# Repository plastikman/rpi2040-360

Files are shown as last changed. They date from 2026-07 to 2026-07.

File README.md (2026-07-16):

# xbox360-rf-rp2040

> ## ✅ Status: WORKING
>
> Drives the Xbox 360 S **Boron Front Panel Module** control bus (start module
> → ring-of-light boot animation → controller sync) from an RP2040-Zero.
>
> **Root cause of a very long bring-up: 3.3V on the wrong pin.** Power must go
> to **pin 8 (`FP_PWR`)**, the module's main rail — **not pin 12
> (`V_3P3STBY`)**, which the schematic labels "3.3V" but is only *standby*
> power. Standby left the chip half-alive: it never clocked, every command
> timed out, the bus sat at a mushy ~2.0V, and USB never enumerated. Move 3.3V
> to **pin 8** and it works with the existing firmware. **If nothing responds,
> confirm 3.3V is on pin 8 — measure pin 8 → GND ≈ 3.3V at the module.**
>
> Wiring (see [`docs/wiring.md`](docs/wiring.md)): **pin 8 = 3.3V, pin 9 = GND,
> pin 2 = DATA → GP3, pin 3 = CLK → GP4, pin 6 = USB D+, pin 5 = USB D−.** Keep
> 1k pull-ups on DATA/CLK.
>
> Diagnostic firmwares from the bring-up live under [`tools/`](tools/).

---

Firmware to drive a salvaged **Xbox 360 S (Slim / "Boron") Front Panel
Module** as a USB PC receiver for wireless Xbox 360 controllers, using a
**Waveshare RP2040-Zero** in place of the console SMC.

Inspired by the [Applied Carbon xboxrf mod](https://www.appliedcarbon.org/xboxrf.html)
(which targets the *phat* RF module), re-implemented for the RP2040 with the
[arduino-pico](https://github.com/earlephilhower/arduino-pico) core.

## What it does

The FPM is itself a self-contained USB device — its USB lines go straight to
the PC. The RP2040 is **not** in the USB data path. It replaces the console
SMC toward the FPM and only:

- reads a **sync button**
- on power-on sends the mandatory Slim **"start module"** command + the
  ring-of-light **boot animation** (visible confirmation the bus works)
- triggers **controller binding** over the FPM's proprietary 2-wire bus

The **module** generates the clock (a **slow** ~hundreds-of-Hz clock on the
Slim, not the phat's ~250 kHz); the host pulls DATA low to start, sets each
bit ~1 ms into the clock-low phase, MSB-first. The Slim needs a mandatory
`0b0000010010` start command before LEDs/sync work, and its sync frame is
**11 bits** (phat's `0b0000000100` + a trailing `1`). Protocol matches the
working [ginokgx/xbox360slimRF](https://github.com/ginokgx/xbox360slimRF).

### Button behaviour

| Action | Result |
|---|---|
| Press | Start controller binding (SYNC) — ring sweeps, then settles on player 1 |

## Hardware

- Waveshare RP2040-Zero (USB-C, dual-core Cortex-M0+, 2MB flash)
- Salvaged Xbox 360 **S (Boron) Front Panel Module**
- 2× 10kΩ pull-up resistors (C_DATA, C_CLK)
- Momentary pushbutton
- USB cable (FPM → PC)
- Printable enclosure: [`hardware/360-rf-board-case-v7.stl`](hardware/360-rf-board-case-v7.stl) (see [`hardware/`](hardware/))

Wiring, full FPM connector pinout, and power rules: see
[`docs/wiring.md`](docs/wiring.md). Short version: the PC cable's 5V powers
the Zero via its `5V` pad, the Zero's `3V3` pad powers the FPM at **pin 8**
(`FP_PWR` — the main rail, **not** pin 12 standby), the USB pair goes to FPM
pins 5/6, and `GP3`/`GP4` are the C_DATA/C_CLK bus.

## Pin map

| RP2040-Zero GPIO | Function | FPM pin |
|---|---|---|
| `GP5` | Sync button (to GND, internal pull-up) | — |
| `GP3` | C_DATA (+10k pull-up) | 2 |
| `GP4` | C_CLK  (+10k pull-up) | 3 |

## Build & flash

Uses the arduino-pico core. FQBN: `rp2040:rp2040:waveshare_rp2040_zero`.

### arduino-cli

```bash
# one-time: add the core
arduino-cli config add board_manager.additional_urls \
  https://github.com/earlephilhower/arduino-pico/releases/download/global/package_rp2040_index.json
arduino-cli core update-index
arduino-cli core install rp2040:rp2040

# compile
arduino-cli compile --fqbn rp2040:rp2040:waveshare_rp2040_zero .

# flash: hold BOOT, tap RESET so the board mounts as a USB drive (RPI-RP2),
# then either upload or drag-drop the .uf2
arduino-cli upload --fqbn rp2040:rp2040:waveshare_rp2040_zero -p /dev/ttyACM0 .
```

### Arduino IDE

1. Add the board manager URL above (Preferences → Additional Boards URLs).
2. Boards Manager → install "Raspberry Pi Pico/RP2040".
3. Select **Waveshare RP2040 Zero**.
4. Open `xbox360-rf-rp2040.ino`, Upload.

## Protocol notes

The Boron FPM two-wire bus and command frames are from community reverse
engineering. Command table lives in [`XboxRF.cpp`](XboxRF.cpp).

- [drtrinity — Reversing the RF board / SMC two-wire interface](https://drtrinity.uk/blog/2025/05/12/reversing-the-rf-board-1) (Slim/Boron, primary source)
- [agarmash.com writeup](https://agarmash.com/posts/xbox-360-controller-receiver/) (phat background)
- [tkkrlab wiki — XBOX 360 RF Module](https://tkkrlab.nl/wiki/XBOX_360_RF_Module) (phat)

## Status — working (controller pairs + registers input)

Confirmed end-to-end: the module **enumerates on USB**, a controller **pairs**
(RP2040 sync button → controller sync) and **registers input** in Windows
`joy.cpl`. On boot the firmware sends the Slim `start module` command then the
ring-of-light **boot animation** (visible confirmation); the sync command
completes over the bus.

**Windows driver:** the module reports `USB\VID_045E&PID_02A9`. Bind the stock
in-box driver by force-picking it — **no `.inf` edit, no signature disable.**
Full steps in **[`docs/windows-driver.md`](docs/windows-driver.md)**; short
version: Device Manager → the device → Update driver → Browse → *Let me pick
from a list* → Microsoft → **Xbox 360 Wireless Receiver for Windows** (accept
the incompatibility warning).

**Ring-of-light:** boot plays the animation and rests on **player 1** lit; a
sync press runs the **searching sweep**, then **all-four flash** (connected),
then settles back to player 1. LED codes were found on-hardware with
[`tools/led-explorer`](tools/led-explorer): `0x088` = sweep, `0x0A1` =
quadrant 1, `0x0C0` = all-four flash. (The RP2040 isn't in the USB-side XInput
player assignment, so it always shows **player 1** — correct for a single
controller.)

Protocol follows [ginokgx/xbox360slimRF](https://github.com/ginokgx/xbox360slimRF):
module-clocked, **slow** clock (hundreds of Hz, not the phat's 250 kHz),
`start module` init `0b0000010010`, ring boot animation `0b0010000101`, 11-bit
sync `0b00000001001`, data set ~1 ms into the clock-low phase, MSB-first.

**The bug that cost the whole bring-up:** 3.3V was on **pin 12
(`V_3P3STBY`, standby power)** instead of **pin 8 (`FP_PWR`, main power)**.
Standby only half-powered the chip — it never clocked, commands timed out, the
bus idled at a mushy ~2.0V, and USB wouldn't enumerate. Fixed by moving 3.3V to
**pin 8**. Lesson: the schematic's "3.3V" pin (12) is *standby*; the module's
logic runs off **pin 8** — verify pin 8→GND ≈ 3.3V at the module.

Diagnostic firmwares (bus-monitor, bus-capture, bus-health, smc-clock-test)
live under [`tools/`](tools/).

## Windows driver

The receiver uses the **official in-box Xbox 360 Wireless Receiver driver** —
force-picked onto the device (`VID_045E&PID_02A9`), no `.inf` editing or
signature-enforcement changes required. Step-by-step: **[`docs/windows-driver.md`](docs/windows-driver.md)**.

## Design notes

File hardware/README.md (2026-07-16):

# Hardware

`360-rf-board-case-v7.stl` — printable enclosure for the Xbox 360 S (Boron)
FPM receiver build (RP2040-Zero + FPM). **v7** is the current revision.

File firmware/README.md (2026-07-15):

# Prebuilt firmware

`xbox360-rf-rp2040.uf2` — compiled binary, ready to flash without a toolchain.

- **Board:** Waveshare RP2040-Zero (`rp2040:rp2040:waveshare_rp2040_zero`)
- **Core:** arduino-pico (earlephilhower) `rp2040:rp2040@5.6.1`
- **Library:** Adafruit NeoPixel `1.15.5` (onboard WS2812 status LED)
- **Built from:** the sketch in the repo root

## Onboard RGB status (WS2812 on GP16)

| Colour | Meaning |
|---|---|
| Solid green | Powered and running (shows immediately on power-up) |
| Blue flash | Sync command sent OK |
| Red flash | Control-bus timeout — FPM didn't respond |

If you see **solid green**, the Zero is powered and the firmware is running —
so any "device doesn't enumerate" problem is on the module/USB side, not the Zero.

## Flash it

1. Hold **BOOT** on the RP2040-Zero, tap **RESET** (or plug in USB-C while
   holding BOOT). It mounts as a USB drive named `RPI-RP2`.
2. Drag `xbox360-rf-rp2040.uf2` onto that drive. The board reboots and runs.

## Rebuild

```bash
arduino-cli lib install "Adafruit NeoPixel"
arduino-cli compile --fqbn rp2040:rp2040:waveshare_rp2040_zero .
```

> Verified working on hardware: module enumerates over USB, controller pairs
> and registers input, and the ring plays boot / sweep / player-1 / connect
> animations. Power **must** go to FPM pin 8 (see the repo README / docs/wiring.md).

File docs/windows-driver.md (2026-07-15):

# Windows driver install

The FPM enumerates as a standard USB device but reports
`USB\VID_045E&PID_02A9`, which the in-box Xbox 360 driver doesn't bind
automatically. You don't need to edit any `.inf` or disable driver-signature
enforcement — just **force-pick the stock Microsoft driver**, which is already
on every Windows 10/11 machine. This is the method that worked here, cleanly.

## Steps (the easy way — no file editing)

1. Connect the receiver's USB to the PC. In **Device Manager** it appears as an
   unknown / "Other" device (⚠️), Hardware ID `USB\VID_045E&PID_02A9`.
2. Right-click it → **Update driver**.
3. **Browse my computer for drivers**.
4. **Let me pick from a list of available drivers on my computer.**
5. If asked for a device category, choose **Xbox 360 Peripherals**
   (or just untick **Show compatible hardware** to see all).
6. Manufacturer **Microsoft** → model **Xbox 360 Wireless Receiver for
   Windows** → **Next**.
7. Accept the **"this driver may not be compatible / not recommended"**
   warning.

The device renames itself to **Xbox 360 Wireless Receiver for Windows** with no
error mark. That's it — the binding **persists across reboots**.

## Verify

1. Press the **sync button** on the adapter (Zero LED flashes blue; the module
   ring does the searching sweep).
2. Press the **sync button on the controller**.
3. The controller connects (its ring settles to a player quadrant).
4. Run **`joy.cpl`** (Win+R → `joy.cpl`) — the controller shows up; sticks and
   buttons register. Or just launch a game.

## Fallback — editing the `.inf` (only if force-pick isn't offered)

Some locked-down Windows setups don't expose the manual driver list. If so:

1. Copy `C:\Windows\System32\DriverStore\FileRepository\xusb22.inf_amd64_*\`
   to a writable folder, e.g. `C:\xbox360driver\`.
2. In `xusb22.inf`, search for `PID_0719`. For each line, add a duplicate below
   it with your PID, e.g.:
   ```
   %XUSB22.DeviceName%=XUSB22_Install, USB\VID_045E&PID_02A9
   ```
   (do it in both `NTamd64` and `NTx86` sections if present; change only the
   PID).
3. Editing the `.inf` breaks its signature, so **disable driver-signature
   enforcement** for the install: Settings → System → Recovery → Advanced
   startup → Restart now → Troubleshoot → Advanced options → Startup Settings →
   Restart → press **7**. Then Update driver → Browse → `C:\xbox360driver\`.

The force-pick method (above) avoids all of this and is strongly preferred.

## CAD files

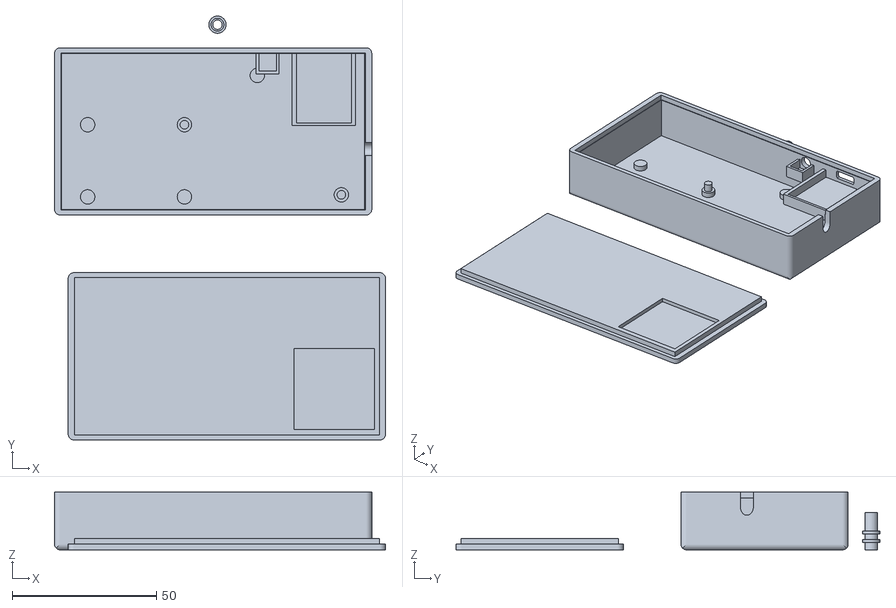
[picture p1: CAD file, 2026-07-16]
hardware/360-rf-board-case-v7.stl
114.8 x 147.0 x 20.0

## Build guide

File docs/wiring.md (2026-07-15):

# Wiring — RP2040-Zero ↔ Xbox 360 S (Boron) FPM

## Principle

The Front Panel Module is a self-contained USB device. Its **USB lines go
straight to the PC** and never touch the RP2040. The RP2040 only drives the
FPM's 2-wire control bus (power LED + controller binding) and reads a sync
button.

## Physical connector layout

As seen on the board — **`■` is the square pad = pin 1** (the pin-1 marker).
Top row 1–6, bottom row 13→7:

```
   ■1    2    3    4    5    6
   13   12   11   10    9    8    7
```

The six wires you actually connect:

```
   pin  signal        connect to
   ---  ------------  ----------------------------
    8   FP_PWR        RP2040 3V3    ⚠ THIS is the 3.3V pin — the module's MAIN
                                     power rail. NOT pin 12 (see warning below).
    9   GND1          RP2040 GND / common ground
    2   C_DATA        RP2040 GP3    (+1k pull-up to 3V3)
    3   C_CLK         RP2040 GP4    (+1k pull-up to 3V3)
    6   D+            PC USB D+ (green)
    5   D−            PC USB D− (white)
   (every other pin — including pin 12 — leave unconnected)
```

> ### ⚠️ Power goes on pin 8, NOT pin 12
> This is the single mistake that cost the entire bring-up. The X819886
> schematic labels **pin 12 = `V_3P3STBY`** (3.3V **standby**) and **pin 8 =
> `FP_PWR`** — but standby power only feeds a tiny always-on domain (enough for
> button sense and a mushy ~2.0V on the bus), **not** the SC14470's main logic.
> Powering pin 12 leaves the chip half-alive: it never clocks, never enumerates
> over USB, and the control bus reads ~2.0V. **Feed 3.3V to pin 8 (FP_PWR) —
> the main rail — and the module comes fully alive.** Verify by measuring
> **pin 8 → GND ≈ 3.3V** at the module.

### Reference: drtrinity's Boron → Pico tap points

The same signals can be tapped from the on-board pad row (between the ribbon
connector and the sync button). This annotated photo maps them by colour:

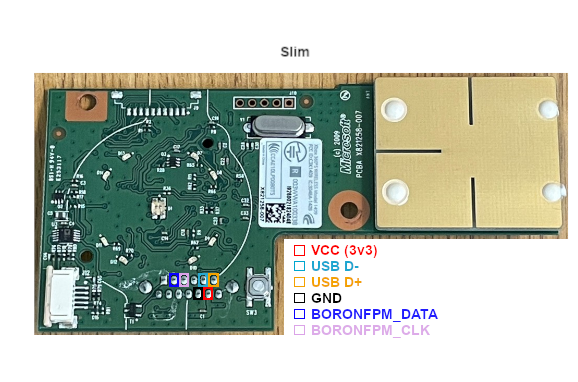
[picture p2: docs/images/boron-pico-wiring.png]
Boron → Pico wiring


> red = VCC (3.3V), black = GND, dark-blue = BORONFPM_DATA, pink =
> BORONFPM_CLK, cyan = USB D−, orange = USB D+.
>
> Image credit: **drtrinity**, *"Reversing the Xbox 360 Front Power Module:
> The SMC Two-Wire Interface"* —
> <https://drtrinity.uk/blog/2025/05/12/reversing-the-rf-board-1>

## Boron FPM connector pinout (X819886-001)

From the official BORON CONN schematic. We use only 6 of the 17 pins.

| Pin | Signal | Direction | Use here |
|----:|---|---|---|
| 1 | FP_TEMP_P | temp sensor | skip |
| **2** | **C_DATA** | control-bus data (BI) | → RP2040 `GP3` (+10k pull-up) |
| **3** | **C_CLK** | control-bus clock (FPM drives) | → RP2040 `GP4` (+10k pull-up) |
| 4 | SPARE1 | — | skip |
| **5** | **D−** | USB differential | → USB to PC |
| **6** | **D+** | USB differential | → USB to PC |
| 7 | FP_TEMP_N | temp sensor | skip |
| **8** | **FP_PWR** | **main 3.3V power** | ← RP2040-Zero `3V3` pad |
| **9** | **GND1** | ground | → GND |
| 10 | ODD_EJECT | eject button out | skip |
| **11** | **GND2** | ground | → GND |
| 12 | V_3P3STBY | 3.3V **standby** (does NOT power the logic) | **skip** — see warning above |
| 13 | BINDSW_N | bind button out | skip (we sync over the bus) |
| 14 | ME1 | mount / GND | GND (optional) |
| 15 | ME2 | mount / GND | GND (optional) |
| 16 | ME3 | mount / GND | GND (optional) |
| 17 | ME4 | mount / GND | GND (optional) |

Note from schematic: `BORONFPMPORT_DX IS A USB DIFFERENTIAL PAIR` (pins 5/6).

## Connections

| RP2040-Zero | ↔ | FPM pin | Notes |
|---|---|---|---|
| `5V` pad | ← | USB VBUS (5V, from the PC cable) | powers the Zero; 5V as **INPUT** |
| `3V3` pad | → | **8** FP_PWR (main 3.3V — NOT pin 12) | Zero's regulator powers the FPM |
| `GND` | ↔ | **9 / 11** (+ ME1–4) | common ground |
| `GP3` | ↔ | **2** C_DATA | + 10kΩ pull-up to 3V3 |
| `GP4` | ← | **3** C_CLK | + 10kΩ pull-up to 3V3 (FPM drives it) |
| `GP5` | ← | sync button → GND | internal pull-up in firmware (moved off GP2) |

### USB routing

The PC's USB cable: **D+ → FPM pin 6, D− → FPM pin 5, GND → pin 9/11**, and
its **5V → the Zero's `5V` pad** (the FPM itself runs on 3.3V from the Zero,
not on USB 5V).

### Pull-ups and decoupling

- The console provides 100kΩ pull-ups on the bus lines *from the motherboard*.
  A salvaged FPM has none, so add **1–10kΩ pull-ups on C_DATA and C_CLK to 3V3**.
- A ~10–100 µF cap across the module's 3.3V (pin 8) / GND near the connector is
  good practice for clean power.

## USB / power rules

- **One 5V source at a time.** Power the Zero from the PC cable's 5V (into the
  `5V` pad). Do **not** also plug the Zero's USB-C into a PC simultaneously —
  the Zero may lack backfeed protection and the rails would fight.
- Use the Zero's **USB-C only for flashing firmware**, module unplugged.

## Before powering on

1. Confirm silkscreen: `3V3` on the Zero is the regulator **output**; feed it
   to FPM **pin 8** (FP_PWR), **not** pin 12. Never put 5V on it.
2. Double-check pins 5/6 (D−/D+) and 2/3 (C_DATA/C_CLK) against your actual
   board with a multimeter — pin numbering/orientation on a bare connector is
   easy to mirror.
3. Verify FPM current draw fits the Zero's LDO headroom (low-power; fine).

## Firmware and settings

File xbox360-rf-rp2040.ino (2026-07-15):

// Xbox 360 S (Slim / "Boron") FPM -> USB desktop adapter, RP2040-Zero edition.
//
// The RP2040 replaces the console SMC toward the Front Panel Module. It is
// NOT in the USB data path: the FPM's USB lines run straight to the PC and
// enumerate on power alone. This firmware only drives the control bus:
//   - power-on: send the mandatory Slim "start module" command, then the
//     ring-of-light boot animation (visible confirmation the bus works)
//   - sync button: trigger controller binding (11-bit Slim sync frame)
//
// Protocol per the working Slim implementation ginokgx/xbox360slimRF: the
// MODULE generates a slow (~hundreds of Hz) clock; we sync to it.
//
// Onboard RGB status (WS2812 on GP16):
//   solid green  -> running
//   blue flash   -> command sent OK
//   red flash    -> control-bus timeout (module didn't clock)
//
// Board: Waveshare RP2040-Zero   FQBN: rp2040:rp2040:waveshare_rp2040_zero
// Wiring/pinout: docs/wiring.md

#include <Adafruit_NeoPixel.h>
#include "XboxRF.h"

constexpr uint8_t PIN_BUTTON = 5;   // sync button to GND (moved off GP2)
constexpr uint8_t PIN_DATA   = 3;   // FPM pin 2  C_DATA
constexpr uint8_t PIN_CLK    = 4;   // FPM pin 3  C_CLK (module drives it)
constexpr uint8_t PIN_RGB    = 16;  // onboard WS2812

constexpr uint16_t DEBOUNCE_MS    = 30;
constexpr uint16_t BOOT_WAIT_MS   = 3500;  // let the FPM boot before talking
constexpr uint16_t CMD_GAP_MS     = 50;
constexpr uint16_t SYNC_WINDOW_MS = 4000;  // searching/pairing window
constexpr uint8_t  INIT_RETRIES   = 30;    // retry init until the FPM answers
constexpr uint8_t  LVL            = 32;

XboxRF rf(PIN_DATA, PIN_CLK);
Adafruit_NeoPixel pixel(1, PIN_RGB, NEO_GRB + NEO_KHZ800);

void led(uint8_t r, uint8_t g, uint8_t b) {
  pixel.setPixelColor(0, pixel.Color(r, g, b));
  pixel.show();
}
void ledIdle() { led(0, LVL, 0); }

void ledResult(bool ok) {
  for (uint8_t i = 0; i < (ok ? 2 : 3); i++) {
    led(ok ? 0 : LVL, 0, ok ? LVL : 0);
    delay(120);
    led(0, 0, 0);
    delay(90);
  }
  ledIdle();
}

void setup() {
  Serial.begin(115200);
  pixel.begin();
  ledIdle();  // green immediately: Zero is powered and running

  pinMode(PIN_BUTTON, INPUT_PULLUP);
  rf.begin();

  delay(BOOT_WAIT_MS);

  // Init with retry: the module isn't always ready at a fixed delay after
  // power-up, and a single attempt that times out would leave the ring dark
  // until a replug. Keep trying until the control-bus commands succeed.
  bool inited = false;
  for (uint8_t attempt = 0; attempt < INIT_RETRIES && !inited; attempt++) {
    bool a = rf.startModule();
    delay(CMD_GAP_MS);
    bool b = rf.bootAnimation();
    inited = a && b;
    Serial.printf("init attempt %d: start=%d boot=%d\n", attempt + 1, a, b);
    if (!inited) {           // brief red blink, then retry
      led(LVL, 0, 0);
      delay(400);
      led(0, 0, 0);
      delay(200);
    }
  }

  if (inited) {
    delay(CMD_GAP_MS);
    rf.ledPlayer1();
  }
  ledResult(inited);
}

void loop() {
  static bool wasDown = false;
  static uint32_t downAt = 0;

  bool isDown = (digitalRead(PIN_BUTTON) == LOW);
  uint32_t now = millis();

  if (isDown && !wasDown) {
    wasDown = true;
    downAt = now;
  } else if (!isDown && wasDown) {
    wasDown = false;
    if (now - downAt >= DEBOUNCE_MS) {
      Serial.println("sync");
      led(0, 0, LVL);            // Zero LED blue while syncing
      rf.sweep();                // ring shows the searching sweep
      bool ok = rf.syncController();
      delay(SYNC_WINDOW_MS);     // pairing window (sweep runs)
      rf.ledAllFlash();          // all-four flash = connected
      delay(1200);
      rf.ledPlayer1();           // settle back to player 1
      ledResult(ok);
    }
  }
}

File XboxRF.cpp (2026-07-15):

#include "XboxRF.h"

// Command frames (MSB-first), from the working Slim implementation
// ginokgx/xbox360slimRF (https://github.com/ginokgx/xbox360slimRF).
//
//   START (0b0000010010) — mandatory Slim "start module" init; without it
//                          the LEDs/sync don't work.
//   BOOT  (0b0010000101) — ring-of-light boot animation (= 0x085).
//   SYNC  (0b00000001001) — phat sync 0b0000000100 + a trailing 1; 11 bits.
//   OFF   (0b0010000000) — LEDs off.
// LED codes verified on-hardware with tools/led-explorer:
//   0x088 = rotating "searching" sweep
//   0x0A1 = quadrant 1 lit (player 1)
//   0x0C0 = all four quadrants flash (sync-complete confirm)
static const uint8_t CMD_START[10]    = {0, 0, 0, 0, 0, 1, 0, 0, 1, 0};
static const uint8_t CMD_BOOT[10]     = {0, 0, 1, 0, 0, 0, 0, 1, 0, 1};  // 0x085
static const uint8_t CMD_SYNC[11]     = {0, 0, 0, 0, 0, 0, 0, 1, 0, 0, 1};
static const uint8_t CMD_SWEEP[10]    = {0, 0, 1, 0, 0, 0, 1, 0, 0, 0};  // 0x088
static const uint8_t CMD_PLAYER1[10]  = {0, 0, 1, 0, 1, 0, 0, 0, 0, 1};  // 0x0A1
static const uint8_t CMD_ALLFLASH[10] = {0, 0, 1, 1, 0, 0, 0, 0, 0, 0};  // 0x0C0
static const uint8_t CMD_OFF[10]      = {0, 0, 1, 0, 0, 0, 0, 0, 0, 0};

XboxRF::XboxRF(uint8_t dataPin, uint8_t clkPin)
    : _data(dataPin), _clk(clkPin) {}

void XboxRF::begin() {
  // Idle: both lines released, held high. External ~1k pull-ups recommended;
  // the module (not this MCU) drives CLK.
  pinMode(_clk, INPUT_PULLUP);
  pinMode(_data, INPUT_PULLUP);
}

void XboxRF::releaseData() {
  digitalWrite(_data, HIGH);
  pinMode(_data, INPUT_PULLUP);
}

// Block until CLK differs from prevLevel (an edge), or timeout.
bool XboxRF::waitClockChange(int prevLevel, uint32_t timeoutUs) {
  uint32_t start = micros();
  while (digitalRead(_clk) == prevLevel) {
    if (micros() - start > timeoutUs) return false;
  }
  return true;
}

bool XboxRF::sendData(const uint8_t* cmd, uint8_t nbits) {
  // Start: pull DATA low while the (module-driven) clock idles high.
  pinMode(_data, OUTPUT);
  digitalWrite(_data, LOW);

  int prev = digitalRead(_clk);  // usually HIGH at idle
  for (uint8_t i = 0; i < nbits; i++) {
    // Wait for the clock to fall...
    if (!waitClockChange(prev, CLK_TIMEOUT_US)) { releaseData(); return false; }
    prev = digitalRead(_clk);

    // ...settle into the low phase, then present the bit.
    delayMicroseconds(1000);
    digitalWrite(_data, cmd[i] ? HIGH : LOW);

    // Wait for the clock to rise (module latches the bit).
    if (!waitClockChange(prev, CLK_TIMEOUT_US)) { releaseData(); return false; }
    prev = digitalRead(_clk);
  }

  releaseData();
  return true;
}

bool XboxRF::startModule()    { return sendData(CMD_START, 10); }
bool XboxRF::bootAnimation()  { return sendData(CMD_BOOT, 10); }
bool XboxRF::syncController() { return sendData(CMD_SYNC, 11); }
bool XboxRF::sweep()          { return sendData(CMD_SWEEP, 10); }
bool XboxRF::ledPlayer1()     { return sendData(CMD_PLAYER1, 10); }
bool XboxRF::ledAllFlash()    { return sendData(CMD_ALLFLASH, 10); }
bool XboxRF::ledsOff()        { return sendData(CMD_OFF, 10); }

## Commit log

2026-07-14 Initial RP2040-Zero firmware for Xbox 360 RF module adapter
    arduino-pico firmware that replaces the original ATtiny25 front-panel
    controller. Reads the sync button and drives the module's 2-wire control
    bus (LED ring, sync, power-off). Not in the USB data path.
    [XboxRF.cpp, xbox360-rf-rp2040.ino]
2026-07-14 Retarget firmware to Xbox 360 S (Boron) Front Panel Module
    The user's salvaged board is a Slim/S FPM, not a phat RF module. Adapt to
    the Boron two-wire control bus per the 2025 drtrinity reverse engineering:
    250 kHz FPM-driven clock, 10-bit ACK+command frame, falling-edge sampling,
    and the Slim command set (power LED, bind/sync, wireless toggle). Document
    the full BORON CONN (X819886-001) pinout in docs/wiring.md.
2026-07-14 Add prebuilt firmware binary (xbox360-rf-rp2040.uf2)
    Compiled with arduino-pico rp2040:rp2040@5.6.1 for the Waveshare
    RP2040-Zero. Shipped so the board can be flashed by drag-drop without a
    local toolchain. 64 KB flash, valid UF2.
2026-07-14 Add WS2812 onboard status LED (green=alive, blue=sync, red=bus timeout)
    The RP2040-Zero has no plain power LED, only a WS2812 RGB on GP16. Drive it
    via Adafruit NeoPixel so a glance confirms the board is powered/running:
    solid green on boot, blue flash on sync OK, cyan on wireless toggle, red
    flash on control-bus timeout. Rebuild the shipped .uf2.
2026-07-14 Add passive bus-monitor diagnostic firmware
    Watches C_DATA/C_CLK without driving them and reports edge activity + idle
    levels over USB serial, plus a WS2812 summary (green=CLK idle high,
    red=CLK stuck low, blue=CLK toggling). For diagnosing why a known-good FPM
    won't respond on the control bus.
    [bus-monitor.ino]
2026-07-14 Add bus-capture mini logic-analyzer firmware
    Records every CLK/DATA transition for ~4s at power-up into RAM and dumps
    them over USB serial, to capture the FPM's power-on handshake burst for
    protocol decoding.
2026-07-14 bus-capture: mirror dump to Serial1 (UART0 on GP0)
    Output now goes to both USB-C CDC and the hardware UART (TX=GP0, 115200)
    so an external USB-serial adapter can read the capture without tying up
    the Zero's USB-C.
2026-07-14 bus-capture: switch to triggered capture (robust to boot timing)
    Sits armed and grabs the burst the instant the bus moves, then re-arms.
    Lets you leave the Zero running and power-cycle only the module to catch
    the FPM power-on handshake, instead of racing the 4s boot window.
2026-07-14 bus-capture: arm immediately (no USB-serial wait)
    Removes the up-to-2s wait for USB CDC so the trigger is armed within ms of
    boot, catching the FPM power-on burst on a shared power cycle. Read the
    dump via the UART adapter (Serial1/GP0), whose COM port survives the cycle.
2026-07-15 Add bus-health live monitor + draft bus-probe
    bus-health continuously attempts a benign control-bus transaction and shows
    green=ok / red=fail live, for finding an intermittent connection by wiggling
    wires. Also includes the active bus-probe draft.
    [bus-health.ino, bus-probe.ino]
2026-07-15 Add smc-clock-test: RP2040 generates the clock
    bus-health proved the FPM never clocks (0% with the FPM-provides-clock
    approach). This test has the RP2040 generate the clock itself and clocks out
    power-LED on/off every 2s so the module's LED can confirm the SMC-as-clock-
    master direction visually.
2026-07-15 Rework driver for the real Slim (Boron) protocol
    Based on the working ginokgx/xbox360slimRF implementation:
    - module generates a SLOW clock (hundreds of Hz, not phat's 250 kHz) -> use
    a generous edge timeout; earlier short timeouts caused false 0% results
    - send the mandatory Slim "start module" command (0b0000010010) at power-on,
    then the ring-of-light boot animation as a visual bus-works check
    - 11-bit sync frame (phat's 0b0000000100 + trailing 1)
    - set data ~1 ms into the clock-low phase, MSB-first, sync to module edges
    Rebuild shipped firmware .uf2.
    [XboxRF.cpp, xbox360-rf-rp2040.ino]
2026-07-15 README: mark as NOT WORKING; needs logic analysis
    The Boron FPM control bus never clocks for us, so no command completes.
    Hardware/wiring/pinout/firmware are all confirmed correct; the blocker is the
    module's undocumented control-bus behavior. No published working reference
    exists for the 13-pin Boron FPM (ginokgx targets a 9-pin phat-style module).
    Unblocking requires a logic-analyzer capture of a live Xbox 360 S console's
    SMC-FPM traffic.
2026-07-15 README: WORKING — root cause was 3.3V on the wrong pad
    Both modules (incl. the one earlier misdiagnosed as dead) work once VCC is on
    the correct pad. Control bus drives start/boot-animation/sync; USB enumerates.
    Document the correct pad-row wiring and the verify-VCC-at-the-module lesson.
2026-07-15 README: confirmed fully working (controller pairs + input)
    USB enumerates, controller pairs and registers in joy.cpl. Document the
    driver force-pick for VID_045E&PID_02A9 and the cosmetic player-quadrant LED
    limitation (RP2040 isn't in the USB-side player assignment).
2026-07-15 Add led-explorer: step through candidate ring LED commands
    Each sync-button press sends the next candidate LED frame and reports it over
    serial, to empirically find the Boron's "spin/searching" animation and the
    "light quadrant 1" command (not documented for the Slim). Findings get baked
    into the main firmware.
2026-07-15 docs: physical connector layout + credited Boron->Pico tap photo
    Add a physical two-row connector diagram (square pad = pin 1) with the six
    wires to connect, flagging pin 12 (V_3P3STBY) as the one that must be right.
    Include drtrinity's annotated Boron->Pico pad-row photo, credited with a link.
2026-07-15 Add ring animations: searching sweep + player-1 + connect flash
    Using LED codes found on-hardware via tools/led-explorer (0x088 sweep,
    0x0A1 quadrant 1, 0x0C0 all-four flash):
    - boot rests on player 1 lit
    - sync button: sweep -> sync -> pairing window -> all-four flash -> player 1
    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
2026-07-15 docs: 3.3V goes to pin 8 (FP_PWR), not pin 12 (V_3P3STBY standby)
    The real root cause: pin 12 is 3.3V STANDBY (feeds only a standby domain, not
    the SC14470 main logic) — powering it left the chip half-alive (no clock, no
    USB, ~2.0V bus). Main power is pin 8 (FP_PWR). Correct all wiring docs/pinout
    tables and the root-cause notes accordingly.
2026-07-15 Move sync button from GP2 to GP5
    Lets a board with a damaged GP2 still be used. DATA/CLK/RGB unchanged
    (GP3/GP4/GP16). Rebuild shipped firmware .uf2 and update docs.
    [xbox360-rf-rp2040.ino]
2026-07-15 tools: move button to GP5 and rebuild all diagnostic uf2s
    bus-monitor and led-explorer used the button on GP2; move both to GP5 to match
    the main firmware (usable on a GP2-damaged board). Recompile and refresh the
    prebuilt .uf2 for all five tools (bus-monitor, bus-capture, bus-health,
    smc-clock-test, led-explorer).
    [bus-monitor.ino, led-explorer.ino]
2026-07-15 docs: add Windows driver install guide (force-pick method)
    Document the exact working install: force-pick the in-box "Xbox 360 Wireless
    Receiver for Windows" driver onto VID_045E&PID_02A9 via Device Manager's
    "let me pick from a list" — no .inf edit, no signature-enforcement disable.
    Include a verify section and the .inf-edit fallback. Link it from the README.
2026-07-15 led-explorer: add control-range candidates for radio/controllers-off
    Append 0x008/0x009/0x00A and 0x010/0x011/0x013 (controller-toggle and
    radio-control range) as indices 22-27 so the "turn radio off" command can be
    found on hardware, to wire onto a long-press.
2026-07-15 docs: remove unsupported long-press/radio-off claim
    The firmware only does short-press sync; there is no long-press or wireless-
    radio toggle. Fix the button-behaviour table and the RGB-status table (drop
    the stale cyan/"wireless toggle" line) to match what actually ships.
2026-07-15 Add printable case STL (hardware/360-rf-board-case.stl)
    Enclosure for the RP2040-Zero + Boron FPM receiver. First print in progress;
    fit not yet verified.
    [360-rf-board-case.stl]
2026-07-15 Retry FPM init at boot until it responds (no more replug roulette)
    The module isn't always ready at a fixed 3.5s post-power-up, and a single
    timed-out attempt left the ring dark until a replug. Retry startModule +
    bootAnimation up to INIT_RETRIES times, blinking red between attempts, then
    settle on player 1 once it answers. Rebuild shipped .uf2.
    [xbox360-rf-rp2040.ino]
2026-07-15 hardware: replace case STL with fixed-fit v6
    Swap 360-rf-board-case.stl for 360-rf-board-case-v6.stl (corrected fit).
    [360-rf-board-case-v6.stl, 360-rf-board-case.stl]
2026-07-16 hardware: update case STL to v7
    [360-rf-board-case-v6.stl, 360-rf-board-case-v7.stl]
2026-07-16 README: link the printable case STL in Hardware
